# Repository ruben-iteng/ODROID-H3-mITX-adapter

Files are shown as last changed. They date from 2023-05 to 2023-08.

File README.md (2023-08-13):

<div align="center" markdown="1">

  <h1>ODROID H3(+) mITX adapter</h1>

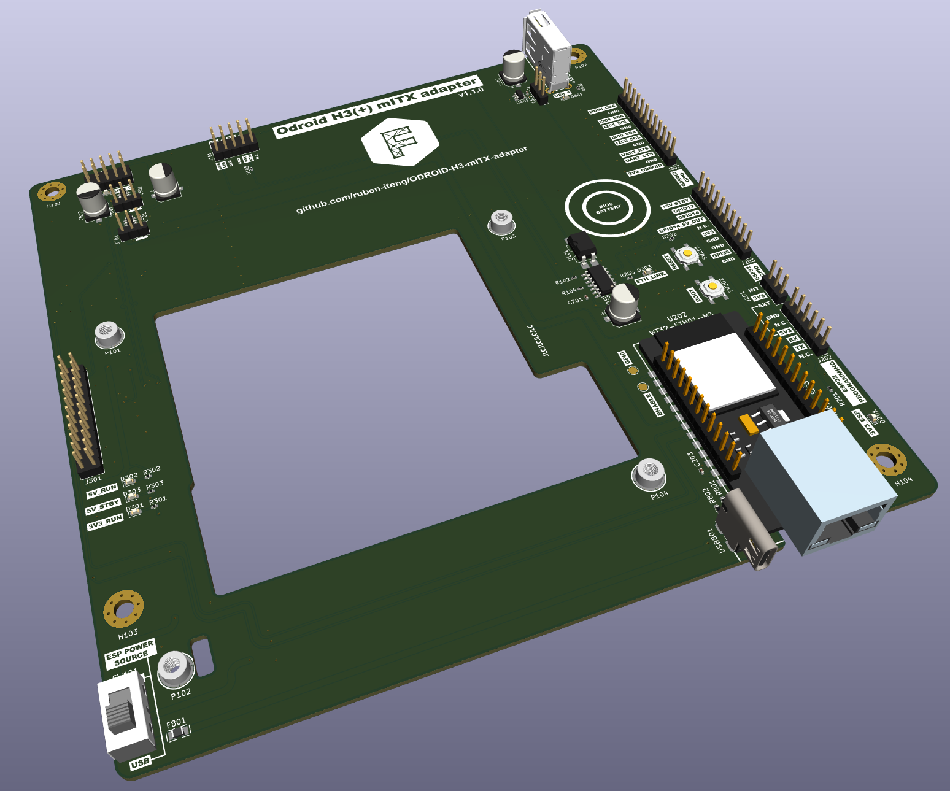
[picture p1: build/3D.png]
3D PCBA
  

  A feature rich mITX adapter for the ODROD H3(+) <br>
  Designed for the [NaSFW project](https://github.com/IoannisP-ITENG/NaSFW)

</div>

## Features

- 1x12 header exposing ODROID GPIO
  - I2C1
  - I2C2
  - HDMI_CEC
  - UART_RTS
  - UART_CTS
- 1x10 header exposing ESP32 GPIO
  - GPIO4
  - GPI36
  - GPIO14
  - GPIO14 5V OUT
  - GPIO12
- 1x6 header exposing ESP32 programming
  - Pin conmpatible with FT232 boards
  - 3V3
  - RX
  - TX
- Front IO
  - 2xUSB2.0 header
  - Front IO header
    - Power LED connected to +5V_RUN
    - HDD connected to ESP32 GPIO4
    - PWR button connected to ODROID
    - RESET button connected to ESP32 GPI39
- On board USB2.0 A connector to ODROID (USB1)
- All USB
  - D+/D- ESD protection
  - VBUS protection
  - VBUS switchable by eitgher
    - ESP32
    - +5V_RUN
- ESP32 with Ethernet
  - Remote UART terminal (BIOS access)
  - 3x USB power control
  - Reset button input
  - PWR_ON button controll of ODROID via optocoupler
  - Always-on, powered by +5V_STBY or USB Type-C PD input

## Manufacturing

Designed for ordering and assembly by JLCPCB

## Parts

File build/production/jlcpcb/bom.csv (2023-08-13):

Designator | Footprint | Quantity | Value | LCSC Part #
C201, C203, C501, C601, C701 | 0402 | 5 | 100nF | C307331
C202, C502, C602, C702 | CP_Elec_6.3x7.7 | 4 | 150uF 10V ±20% | C249851
D201, D501, D601, D701 | 0603 | 4 | 3V3_ESP32 | C165981
D203 | 0603 | 1 | ETH_LINK | C165981
D301 | 0603 | 1 | 3V3_RUN | C165981
D302 | 0603 | 1 | 5V_RUN | C165981
D303 | 0603 | 1 | 5V_STBY | C165981
F801 | F0805 | 1 | BSMD0805-110-6V | C883113
H101, H102, H103, H104 | MountingHole_4mm_Pad_Via | 4 | MountingHole_Pad
J101, J401 | PinHeader_2x05_P2.54mm_Vertical | 2 | Conn_02x05_Odd_Even | C2829881
J201, J501, J601, J701 | PinHeader_1x03_P2.54mm_Vertical | 4 | Conn_01x03 | C358685
J202 | PinHeader_1x06_P2.54mm_Vertical | 1 | Conn_01x06 | C2761399
J203 | PinHeader_1x10_P2.54mm_Vertical | 1 | Conn_01x10 | C706882
J301 | PinHeader_2x12_P2.54mm_Vertical | 1 | Conn_02x12_Odd_Even | C2935922
J302 | PinHeader_1x12_P2.54mm_Vertical | 1 | Conn_01x12 | C225487
P101, P102, P103, P104 | SMD_BD5.6-D4.1 | 4 | SMTSO3035CTJ | C2916333
R101, R103 | 0402 | 2 | 1K | C11702
R102, R104, R201, R205, R301, R302, R303, R501, R601, R701 | 0402 | 10 | 100R | C25076
R202, R203 | 0402 | 2 | 100K | C25086
R801, R802 | 0603 | 2 | 5.1K | C3152148
SW101 | SW-TH_SS-12D10L3 | 1 | SS-12D10L3 | C319013
SW201, SW202 | SW-SMD_4P-L5.1-W5.1-P3.70-LS6.5-TL-2 | 2 | TS-1187A-B-A-B | C318884
TP201 | TestPoint_Pad_D2.0mm | 1 | ENABLE
TP202 | TestPoint_Pad_D2.0mm | 1 | GPI0
U101 | SMDIP-4_W9.53mm | 1 | LTV-817S | C106900
U201 | SOIC-14_3.9x8.7mm_P1.27mm | 1 | CD74HCT125M96 | C133797
U202 | WT32-ETH01 | 1 | WT32-ETH01-M3
U501, U601, U701 | SOT-23-6 | 3 | TPD3S014 | C87384
USB401 | USB-226-BRY | 1 | USB-226-BRY
USB801 | USB-TYPE-C-TH_918-518K2023D5000X | 1 | 918-518K2023D50001 | C399934

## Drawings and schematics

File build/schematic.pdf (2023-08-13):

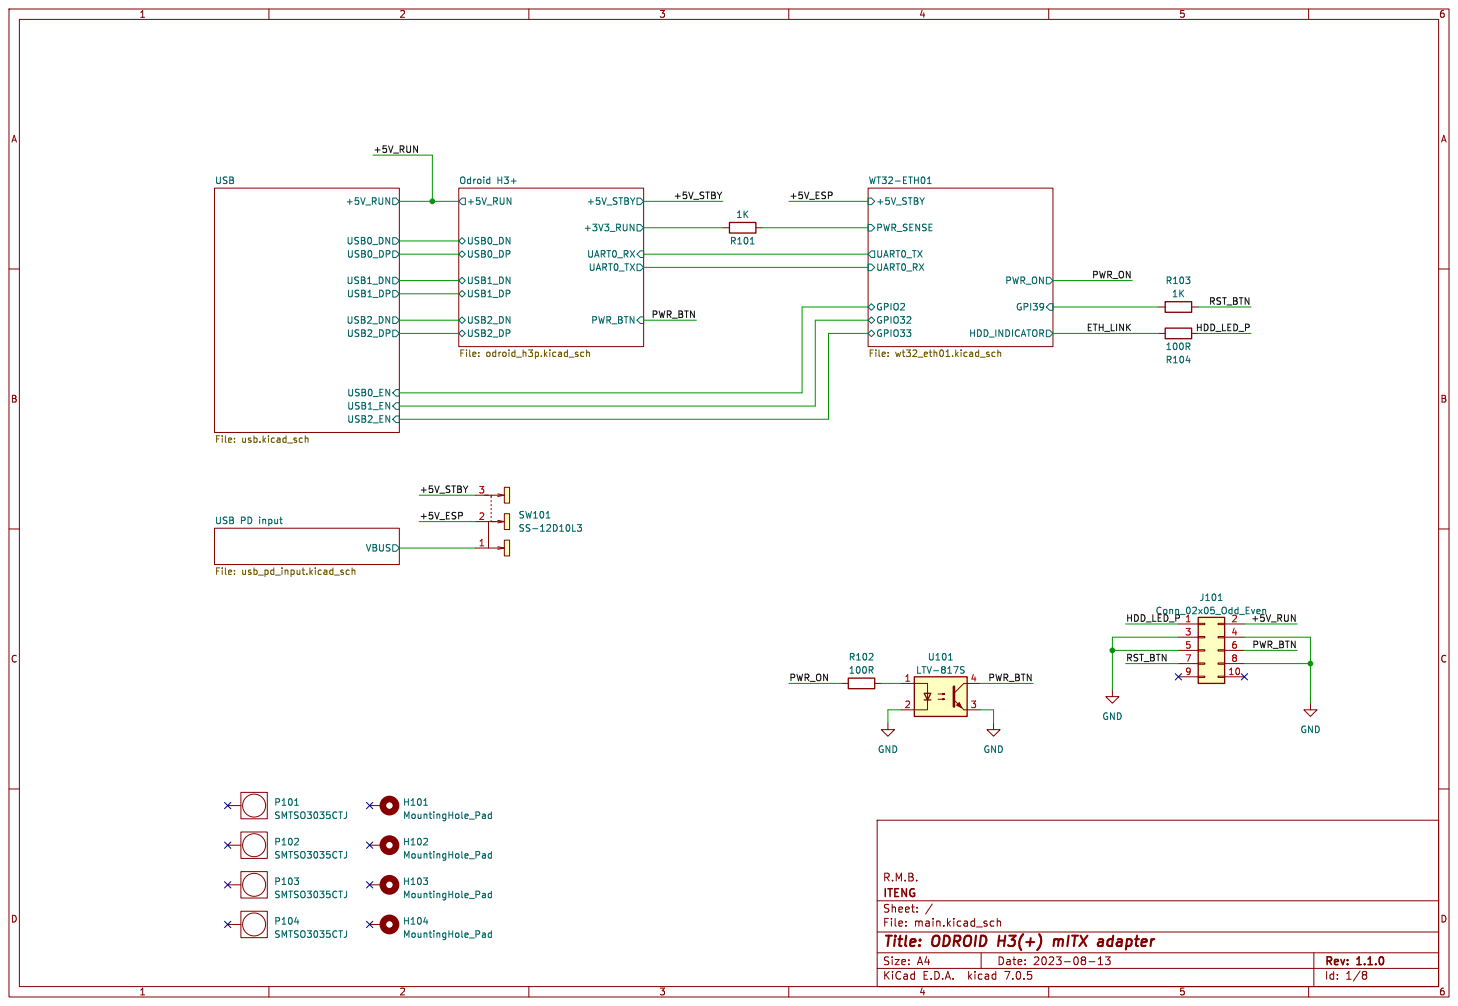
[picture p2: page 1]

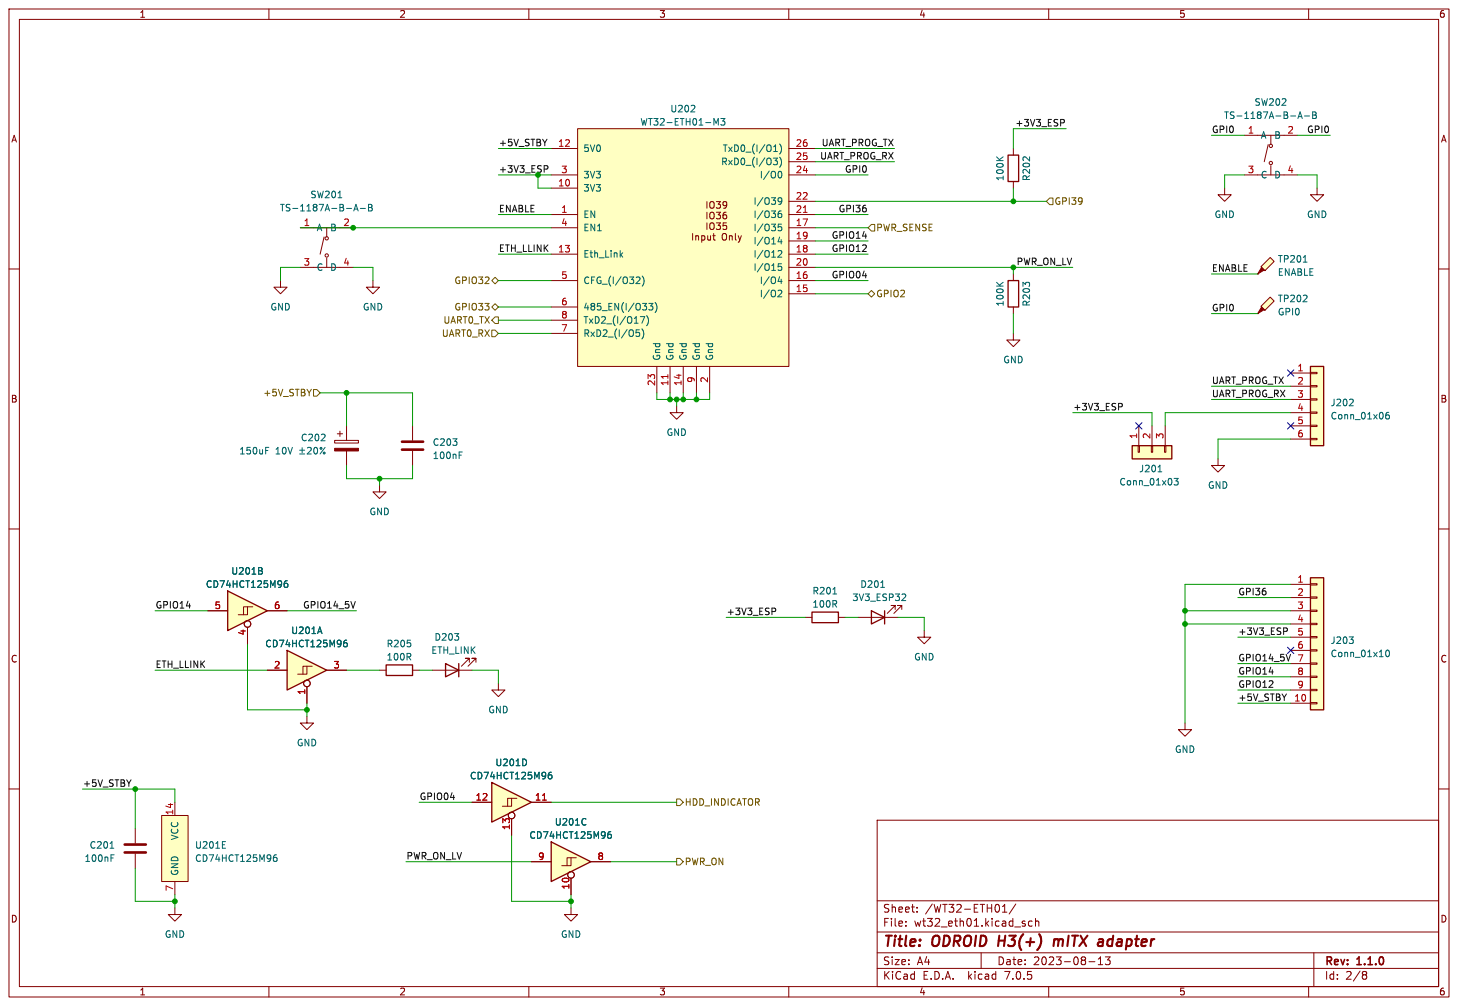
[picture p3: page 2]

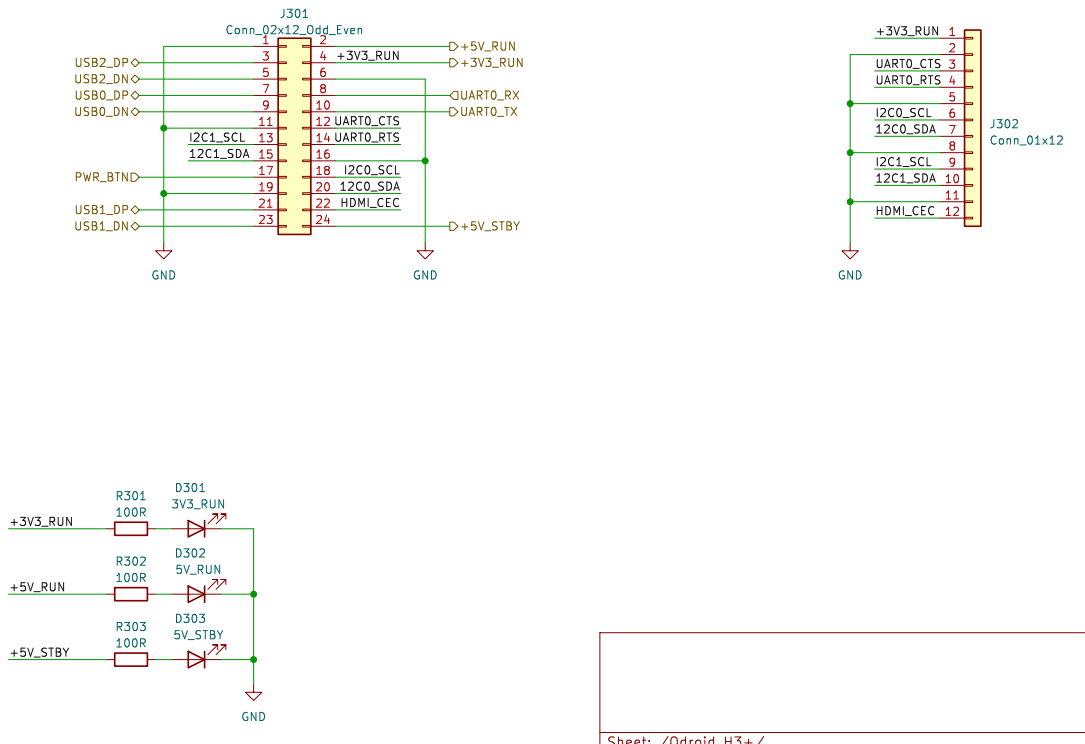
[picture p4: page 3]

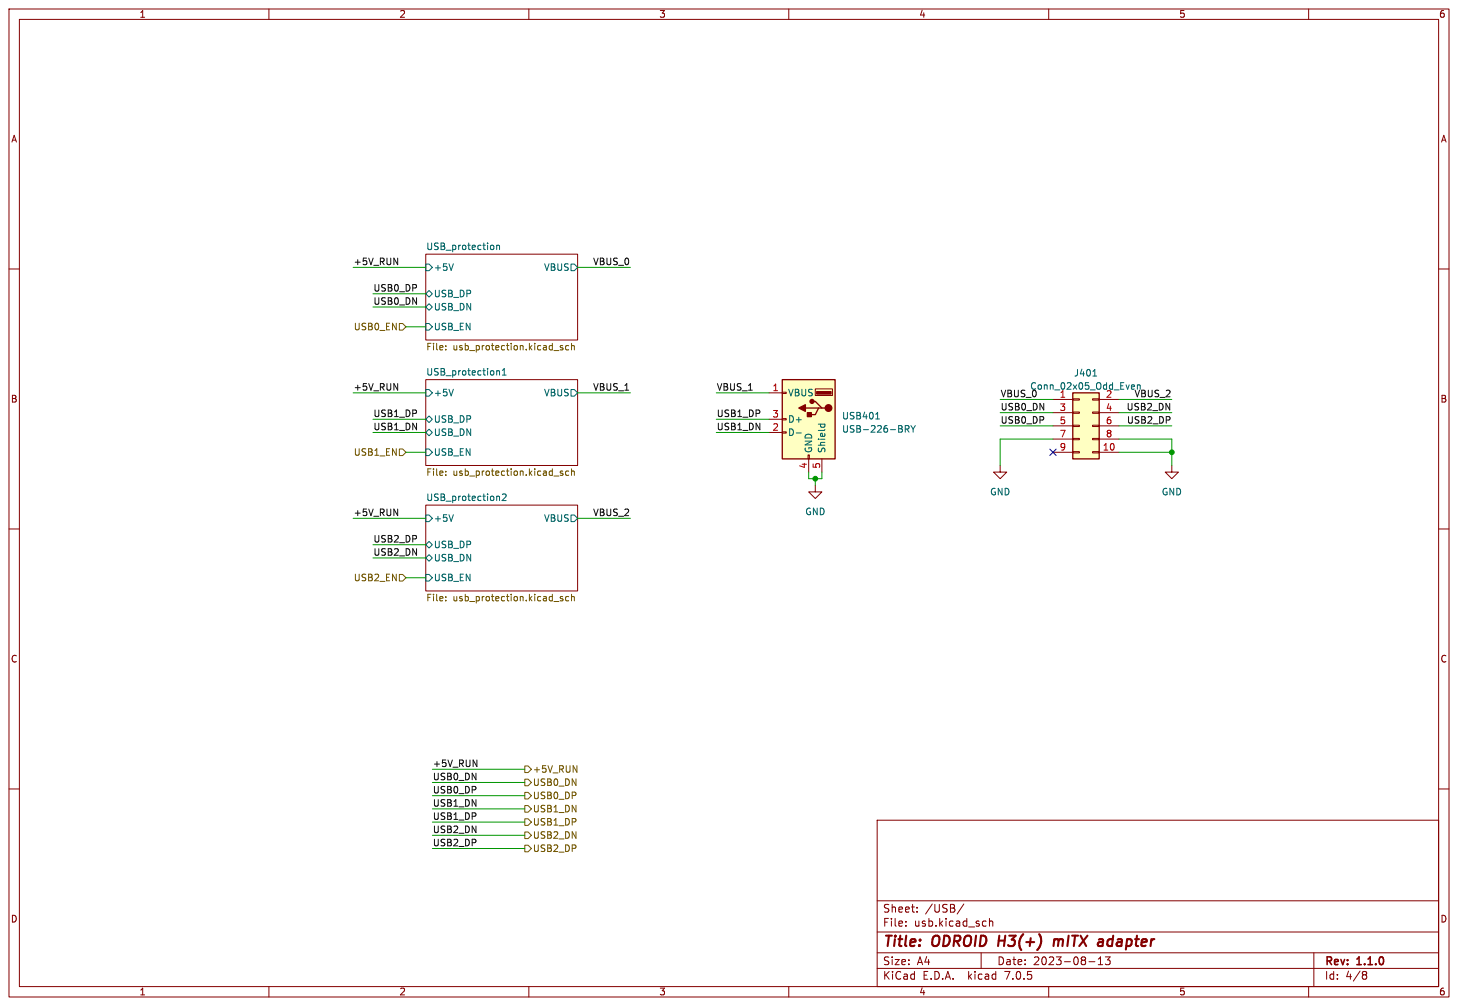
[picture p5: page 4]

5 USB401 USB-226-BRY GND GND

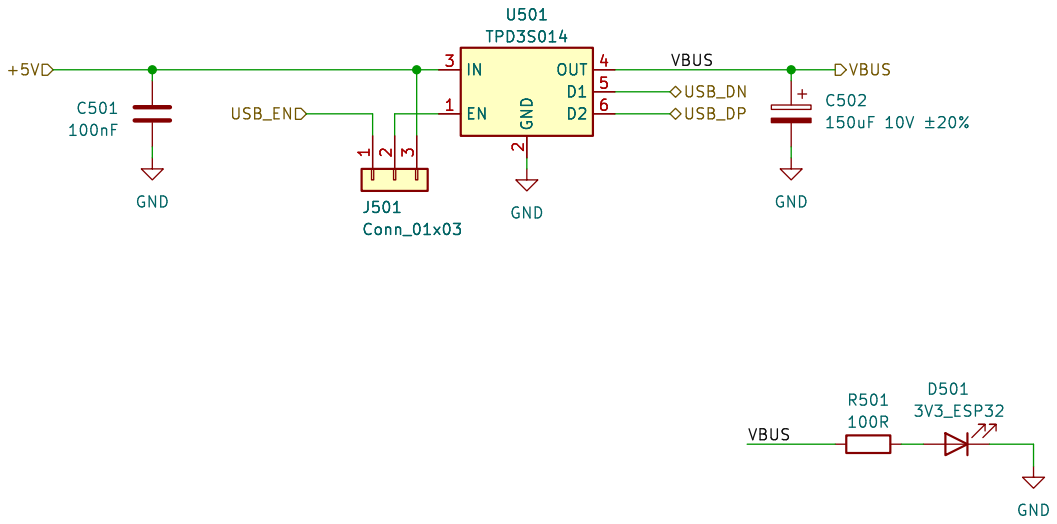
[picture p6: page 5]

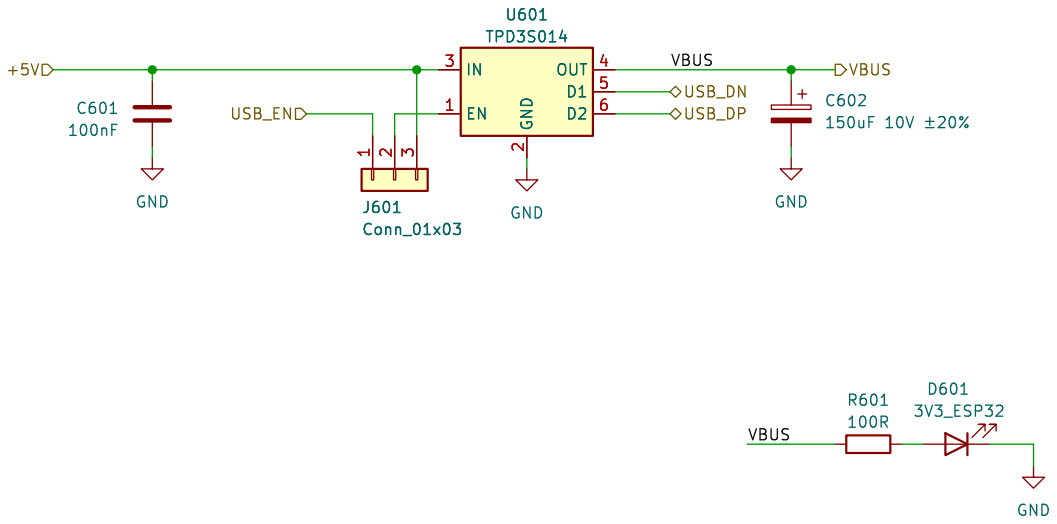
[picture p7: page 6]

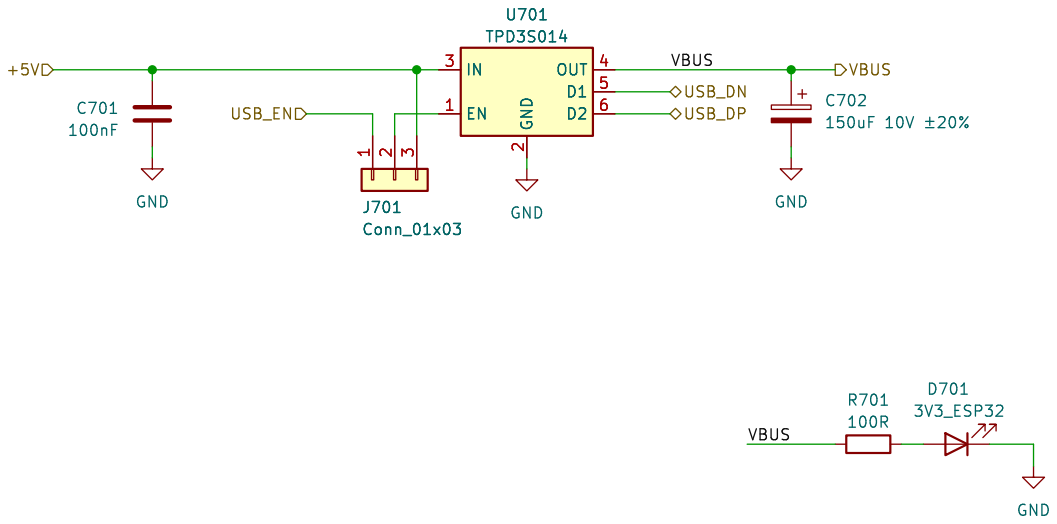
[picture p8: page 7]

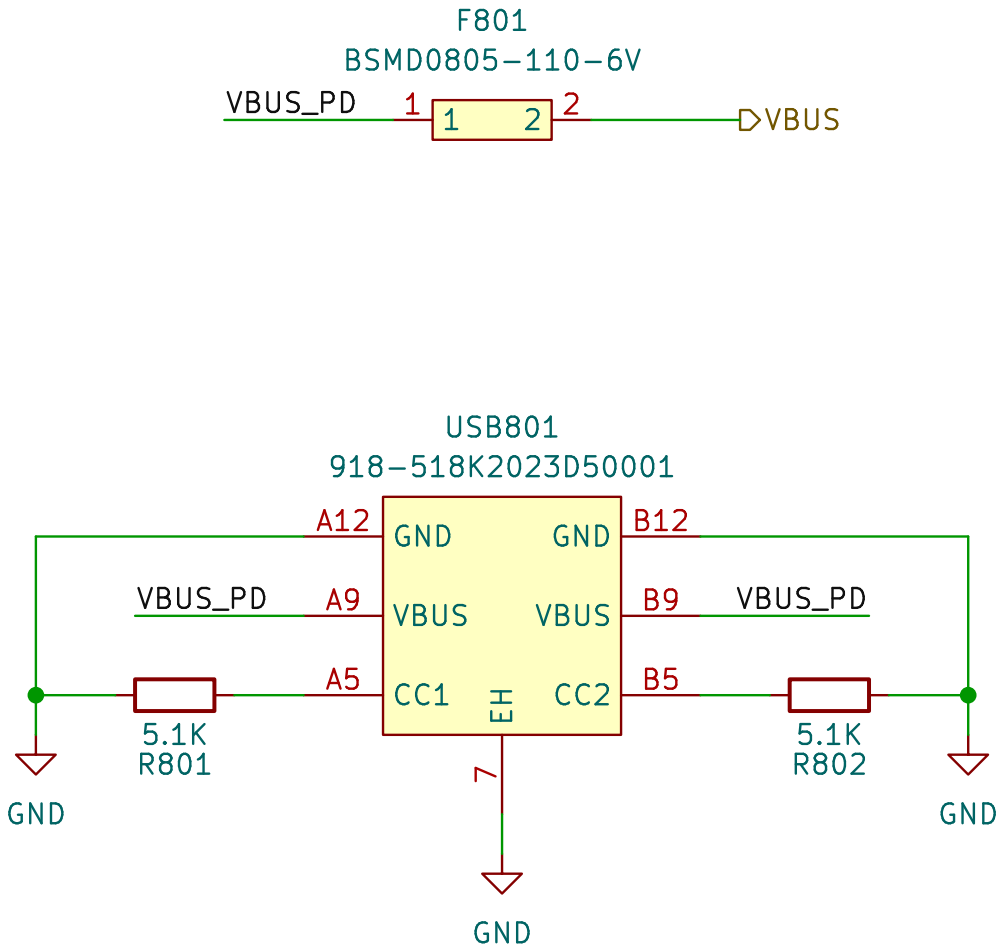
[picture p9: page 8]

7 GND A12 CC1 A5 VBUS A9 GND B12 CC2 B5 VBUS B9 USB801

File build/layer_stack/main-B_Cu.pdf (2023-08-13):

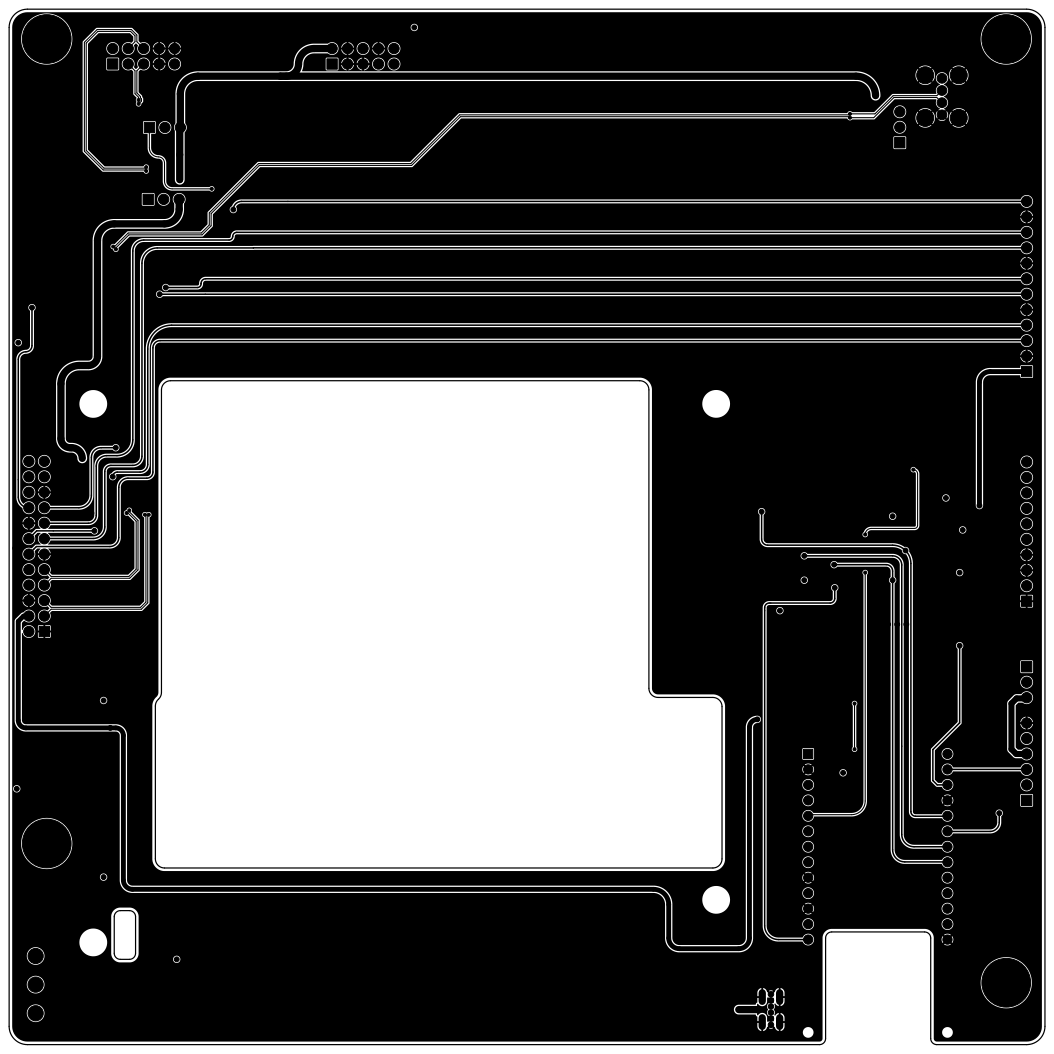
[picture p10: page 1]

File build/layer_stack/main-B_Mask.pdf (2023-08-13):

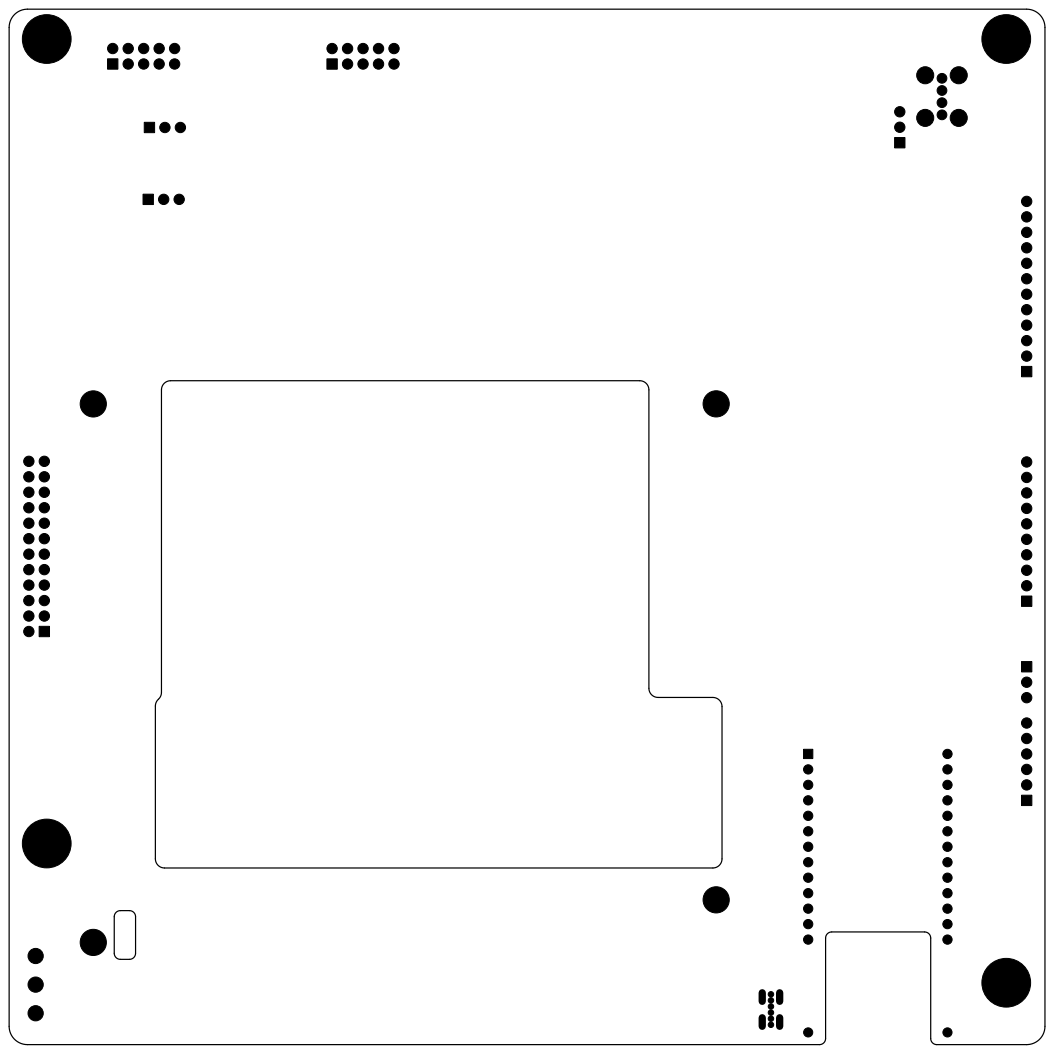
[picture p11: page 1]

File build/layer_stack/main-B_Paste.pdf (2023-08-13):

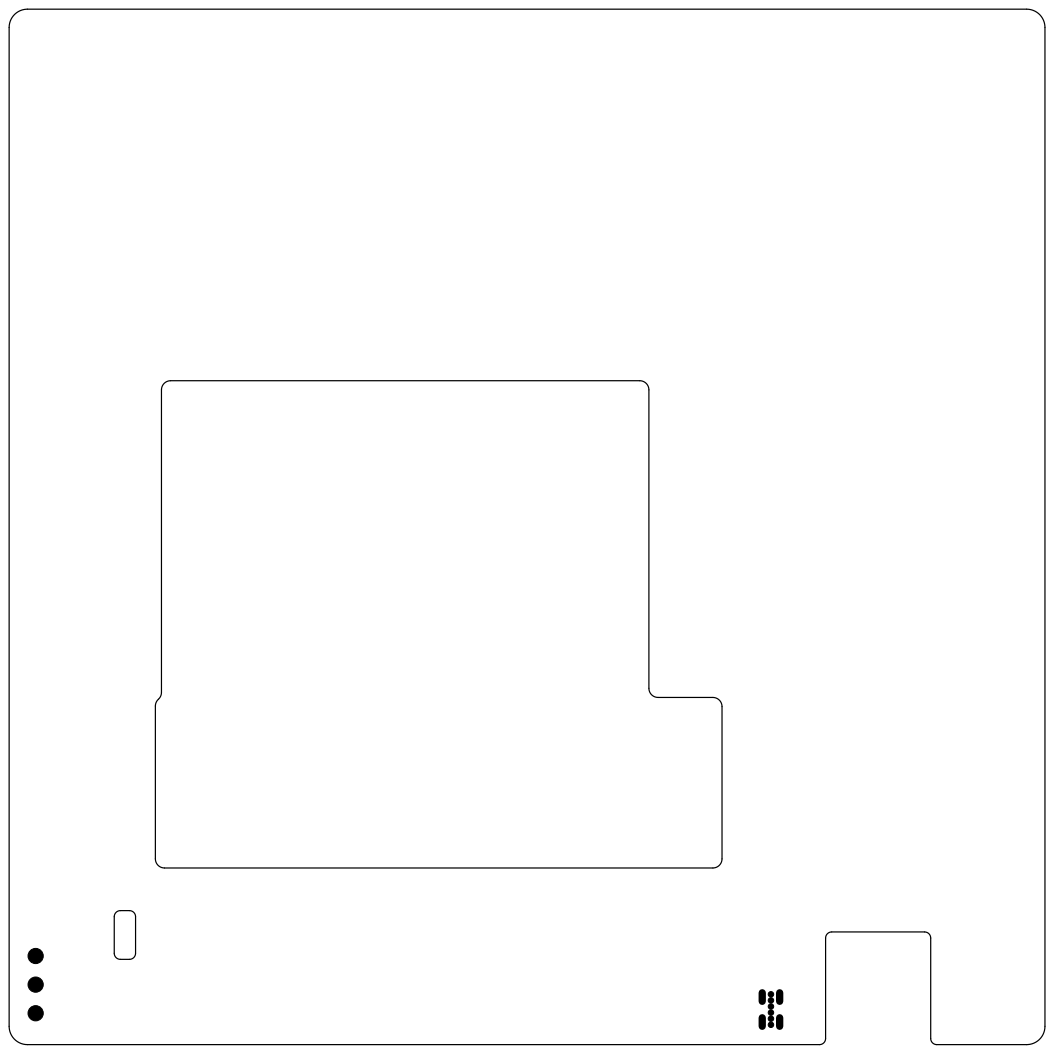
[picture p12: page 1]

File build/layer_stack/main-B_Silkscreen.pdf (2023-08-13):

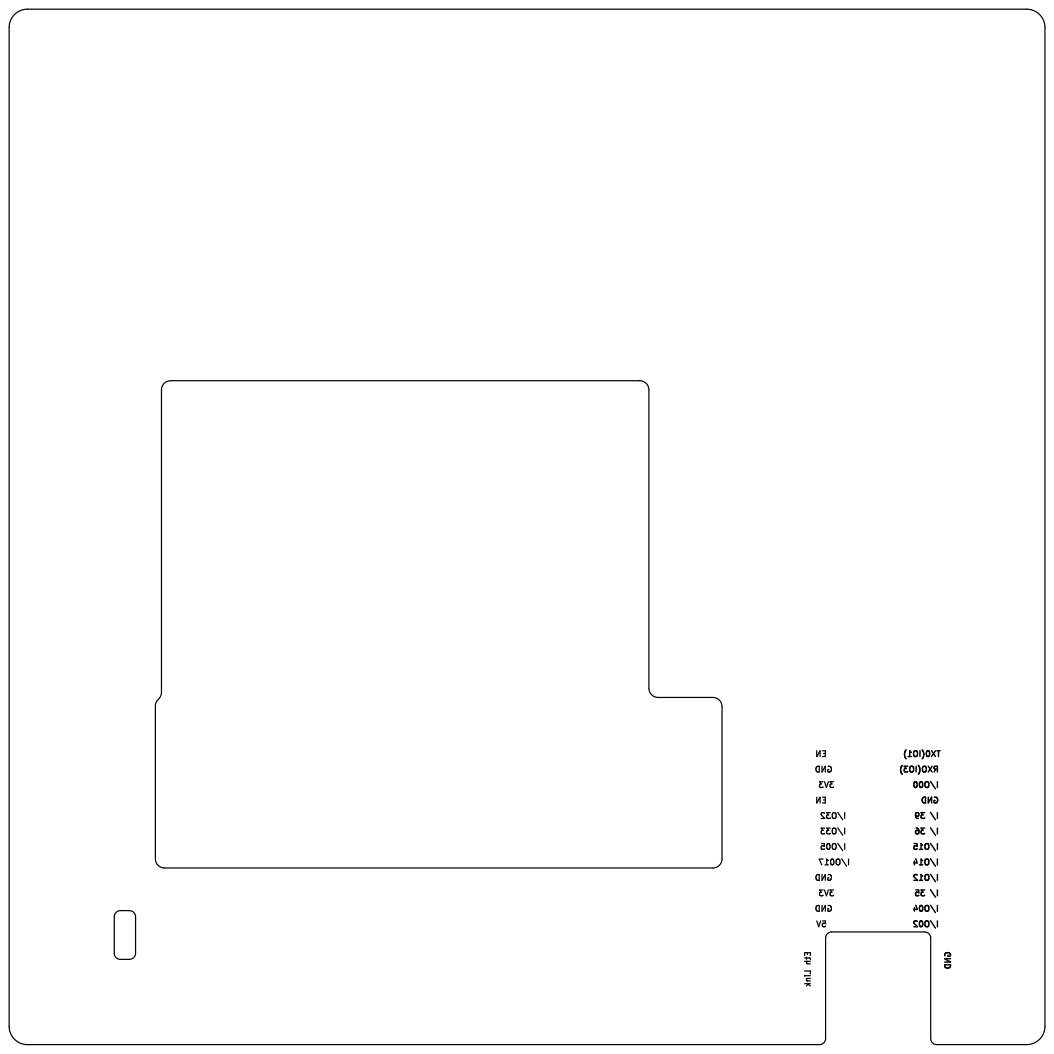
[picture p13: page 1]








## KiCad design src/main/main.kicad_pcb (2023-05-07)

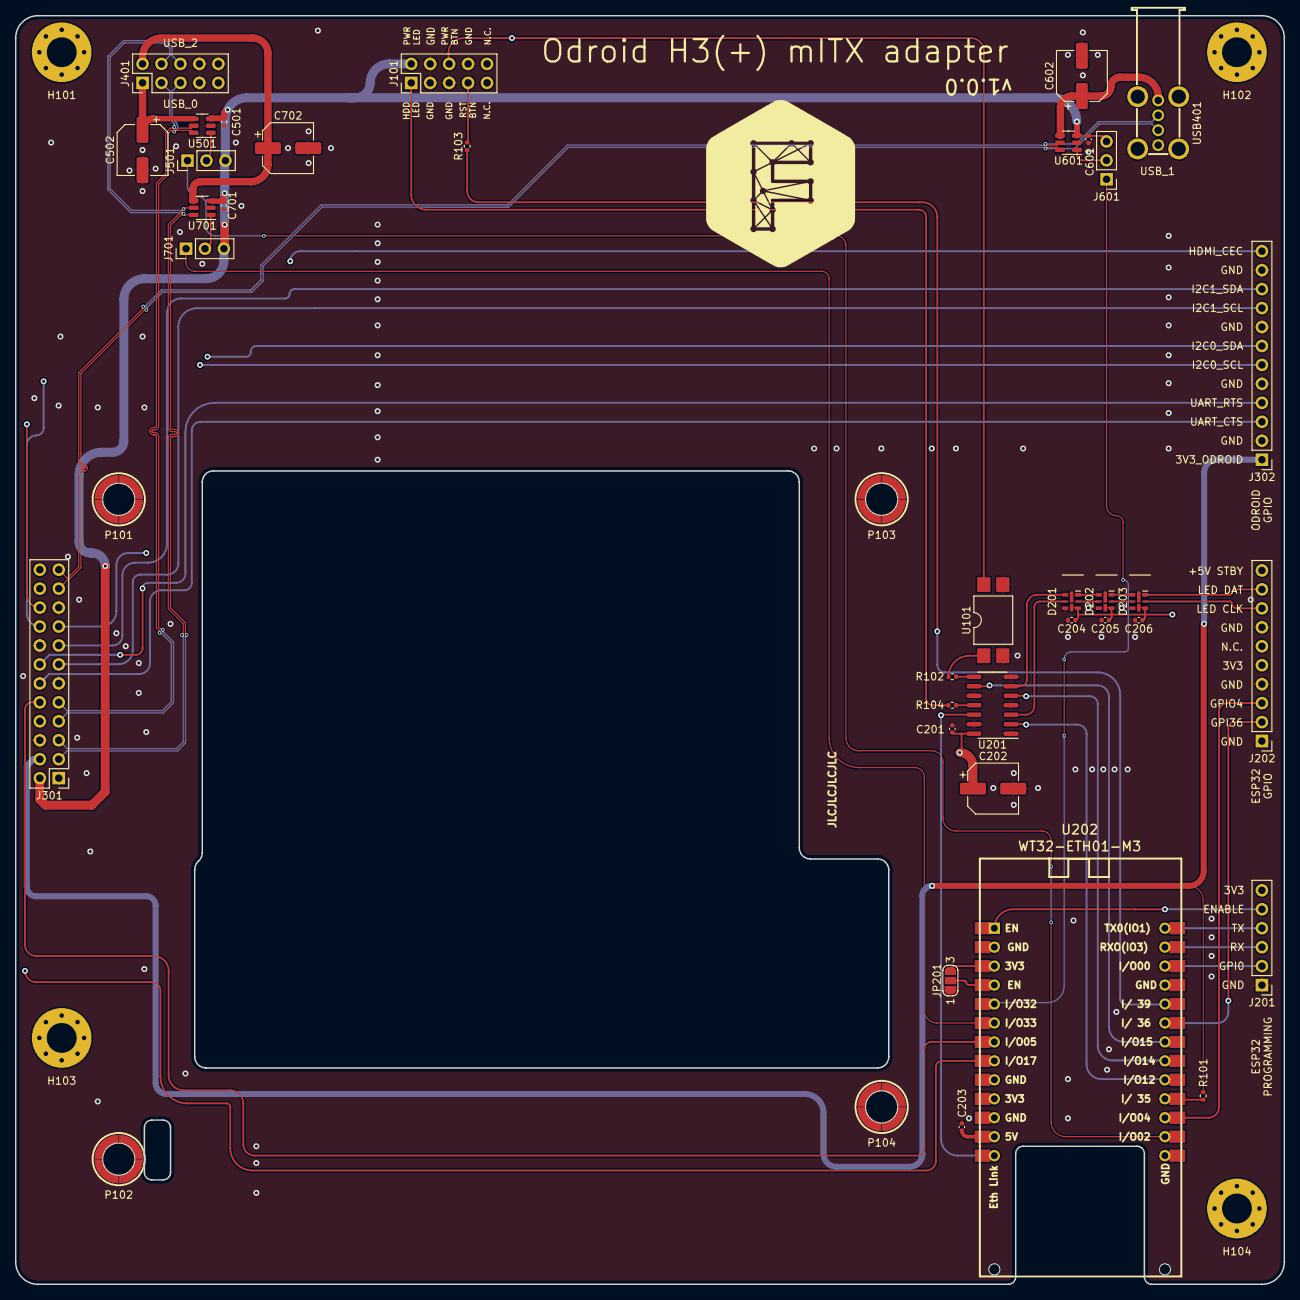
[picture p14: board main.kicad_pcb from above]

Board: 4 copper layers, 170.0 x 170.0 mm, 44 parts (0 on the bottom side), 56 nets.

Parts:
C201, C203, C204, C205, C206, C501, C601, C701: 100nF; C_0402_1005Metric
C202, C502, C602, C702: 150uF 10V ±20%; CP_Elec_6.3x7.7
D201, D202, D203: APA102-2020; LED-APA102-2020
H101, H102, H103, H104: MountingHole_Pad; MountingHole_4mm_Pad_Via
J101, J401: Conn_02x05_Odd_Even; PinHeader_2x05_P2.54mm_Vertical
J201: Conn_01x06; PinHeader_1x06_P2.54mm_Vertical
J202: Conn_01x10; PinHeader_1x10_P2.54mm_Vertical
J301: Conn_02x12_Odd_Even; PinHeader_2x12_P2.54mm_Vertical
J302: Conn_01x12; PinHeader_1x12_P2.54mm_Vertical
J501, J601, J701: Conn_01x03; PinHeader_1x03_P2.54mm_Vertical
JP201: Jumper_3_Open; SolderJumper-3_P1.3mm_Open_RoundedPad1.0x1.5mm_NumberLabels
P101, P102, P103, P104: SMTSO3035CTJ; SMD_BD5.6-D4.1
R101, R103: 1K; R_0402_1005Metric
R102, R104: 100R; R_0402_1005Metric
U101: LTV-817S; SMDIP-4_W9.53mm
U201: CD74HCT125M96; SOIC-14_3.9x8.7mm_P1.27mm
U202: WT32-ETH01-M3; WT32-ETH01
U501, U601, U701: TPD3S014; SOT-23-6
USB401: USB-226-BRY

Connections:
/+5V_RUN: C501.1, C601.1, C701.1, J101.2, J301.2, J501.3, J601.3, J701.3, U501.3 (IN), U601.3 (IN), U701.3 (IN)
/ETH_LINK: R104.1, U201.11
/HDD_LED_P: J101.1, R104.2
/Odroid H3+/12C0_SDA: J301.20, J302.7
/Odroid H3+/12C1_SDA: J301.15, J302.10
/Odroid H3+/+3V3_RUN: J301.4, J302.1, R101.2
/Odroid H3+/HDMI_CEC: J301.22, J302.12
/Odroid H3+/I2C0_SCL: J301.18, J302.6
/Odroid H3+/I2C1_SCL: J301.13, J302.9
/Odroid H3+/UART0_CTS: J301.12, J302.3
/Odroid H3+/UART0_RTS: J301.14, J302.4
/Odroid H3+/UART0_RX: J301.8, U202.8 (TxD2_(I/O17))
/Odroid H3+/UART0_TX: J301.10, U202.7 (RxD2_(I/O5))
/PWR_BTN: J101.6, J301.17, U101.4
/PWR_ON: R102.1, U201.8
/RST_BTN: J101.7, R103.2
/USB/USB0_DN: J301.9, J401.3, U501.5 (D1)
/USB/USB0_DP: J301.7, J401.5, U501.6 (D2)
/USB/USB0_EN: J501.1, U202.15 (I/O2)
/USB/USB1_DN: J301.23, U601.5 (D1), USB401.2 (D-)
/USB/USB1_DP: J301.21, U601.6 (D2), USB401.3 (D+)
/USB/USB1_EN: J601.1, U202.5 (CFG_(I/O32))
/USB/USB2_DN: J301.5, J401.4, U701.5 (D1)
/USB/USB2_DP: J301.3, J401.6, U701.6 (D2)
/USB/USB2_EN: J701.1, U202.6 (485_EN(I/O33))
/USB/VBUS_0: C502.1, J401.1, U501.4 (OUT)
/USB/VBUS_1: C602.1, U601.4 (OUT), USB401.1 (VBUS)
/USB/VBUS_2: C702.1, J401.2, U701.4 (OUT)
/WT32-ETH01/+3V3_ESP: J201.6, J202.5, JP201.3 (B), U202.3 (3V3), U202.10 (3V3)
/WT32-ETH01/+5V_STBY: C201.1, C202.1, C203.1, C204.1, C205.1, C206.1, D201.1 (VDD), D202.1 (VDD), D203.1 (VDD), J202.10, J301.24, U201.14 (VCC), U202.12 (5V0)
/WT32-ETH01/ENABLE: J201.5, U202.1 (EN)
/WT32-ETH01/ETH_LLINK: U201.12, U202.13 (Eth_Link)
/WT32-ETH01/GPI0: J201.2, U202.24 (I/O0)
/WT32-ETH01/GPI36: J202.2, U202.21 (I/O36)
/WT32-ETH01/GPI39: R103.1, U202.22 (I/O39)
/WT32-ETH01/GPIO04: J202.3, U202.16 (I/O4)
/WT32-ETH01/LED_CLK_HV: D201.5 (CKI), U201.3
/WT32-ETH01/LED_CLK_LV: U201.2, U202.18 (I/O12)
/WT32-ETH01/LED_CLOCK_OUT: D203.2 (CKO), J202.8
/WT32-ETH01/LED_DATA_OUT: D203.3 (SDO), J202.9
/WT32-ETH01/LED_DAT_HV: D201.4 (SDI), U201.6
/WT32-ETH01/LED_DAT_LV: U201.5, U202.19 (I/O14)
/WT32-ETH01/PWR_ON_LV: U201.9, U202.20 (I/O15)
/WT32-ETH01/PWR_SENSE: R101.1, U202.17 (I/O35)
/WT32-ETH01/UART_PROG_RX: J201.3, U202.25 (RxD0_(I/O3))
/WT32-ETH01/UART_PROG_TX: J201.4, U202.26 (TxD0_(I/O1))
GND: C201.2, C202.2, C203.2, C204.2, C205.2, C206.2, C501.2, C502.2, C601.2, C602.2, C701.2, C702.2, D201.6 (GND), D202.6 (GND), D203.6 (GND), J101.3, J101.4, J101.5, J101.8, J201.1, J202.1, J202.4, J202.7, J301.1, J301.6, J301.11, J301.16, J301.19, J302.2, J302.5, J302.8, J302.11, J401.7, J401.8, J401.10, JP201.1 (A), U101.2, U101.3, U201.1, U201.4, U201.7 (GND), U201.10, U201.13, U202.2 (Gnd), U202.9 (Gnd), U202.11 (Gnd), U202.14 (Gnd), U202.23 (Gnd), U501.2 (GND), U601.2 (GND), U701.2 (GND), USB401.4 (GND), USB401.5 (Shield)
unnamed: D201.2 (CKO), D202.5 (CKI)
unnamed: D201.3 (SDO), D202.4 (SDI)
unnamed: D202.2 (CKO), D203.5 (CKI)
unnamed: D202.3 (SDO), D203.4 (SDI)
unnamed: J501.2, U501.1 (EN)
unnamed: J601.2, U601.1 (EN)
unnamed: J701.2, U701.1 (EN)
unnamed: JP201.2 (C), U202.4 (EN1)
unnamed: R102.2, U101.1

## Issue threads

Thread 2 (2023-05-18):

v1.1.0 changes and bugfixes

ruben-iteng, 2023-05-18:
- [x] J201 programming header
  - [x] Add reset button
  - [x] Add enable button
  - [x] Make pinout compatible with USB-UART boards
    - [X] Move GPI0 and ENABLE to testpoints
- [x] Add power rail LED status indicators
  - [x] 3V3_RUN
  - [x] 3V3_ESP32
  - [x] 5V_RUN
  - [x] 5V_STBY
  - [X] VBUS_[1-3]
- [x] JP201 remove, this pin is ESP32 RESET (connect to button)
- [ ] J301 Fix alignment with ODROID connector
- [x] GPIO39 needs external pullup to 3V3
- [x] Add pulldown to PWR_BUTTON optocoupler (GPIO15) to set default to disconnected (in hardware)
- [ ] GPIO 12 and 15 are strapping pins and should be avoided

Closed 2023-08-13.

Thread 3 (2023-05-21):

APA102 LEDs are not working

ruben-iteng, 2023-05-21:
Tested with various configurations using ESPHome

Closed 2023-08-13.

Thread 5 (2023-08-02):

Choose power source ESP32

Edgar-ZP, 2023-08-02:
It would be nice if you can choose the power source of the ESP32 by a jumper setting.
Default is from the Ordroid board, but an ESP32 with POE would be an other option.

Closed 2023-08-13.

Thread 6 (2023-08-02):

An extra DC power feed

Edgar-ZP, 2023-08-02:
It would be nice if the board could be powered from two DC Feeds (failover).

ruben-iteng, 2023-08-11:
Adding an extra USB Type-C connector and using [this](https://amzn.eu/d/ggrDDfH) PoE adapter might be a nice solution.
This would require a power selector switch or circuit for the ESP32 power.

Closed 2023-08-13.

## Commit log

2023-05-07 rev1.0.0 (#1)
    A feature rich mITX adapter for the ODROD H3(+)
    [bom.csv, designators.csv, main.kicad_pcb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]
2023-08-13 Rev1.1.0: (#7)
    Add:
    - Power rail LED status indicators
    - Buffered LED on ETH_LINK
    - GPIO14 and GPIO12 on header
    - GPIO14 5V buffered output on header
    - Testpoints for GPIO0 and ESP32_ENABLE pin
    - Reset and Boot switches
    - ESP PWR selector switch
    - USB Type-C PD input (5V) for ESP32
    - 1.1A Fuse for USB PD input
    - Add spot for BIOS battery on silk
    - Add silkscreen default jumper marking
    - Add GPIO39 external pullup to 3V3
    - Add pulldown to PWR_BUTTON (GPIO15)
    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
    [bom.csv, designators.csv, main.kicad_sch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]
